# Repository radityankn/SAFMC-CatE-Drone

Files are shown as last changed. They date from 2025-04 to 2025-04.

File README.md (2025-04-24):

# SAFMC-CatE-Drone
A repository for SAFMC Cat E 2025 Drone Design. It consist of Hardware, Software, and Firmware file. The drone is incomplete though, as lack of funds and increased difficulty of development continue to prevent the team from completing it, leading to its early withdrawal from the competition

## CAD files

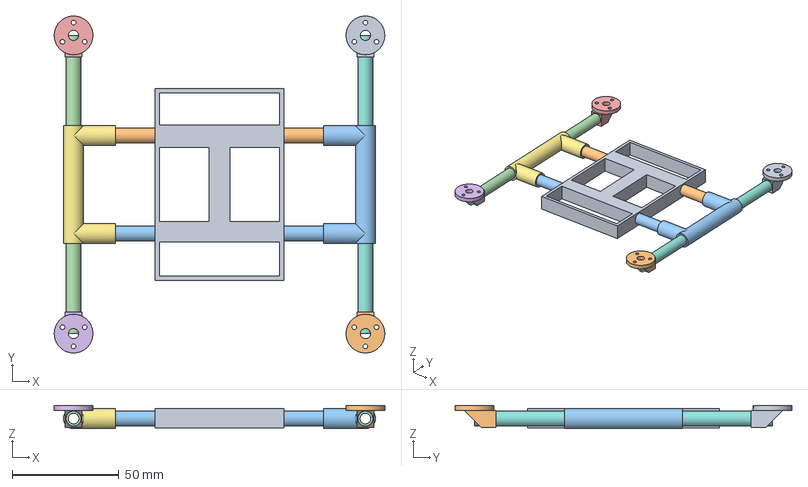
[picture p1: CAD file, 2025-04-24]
Airframe_CatE/Frame Drone_2.FCStd
155.2 x 158.2 x 11.0 mm
Le Platform
Arm_front
Arm_back
Arm_left
Arm_MotorMount001
Arm_MotorMount003
C Joint_Left
Arm_right
Arm_MotorMount
Arm_MotorMount002
C Joint_Right

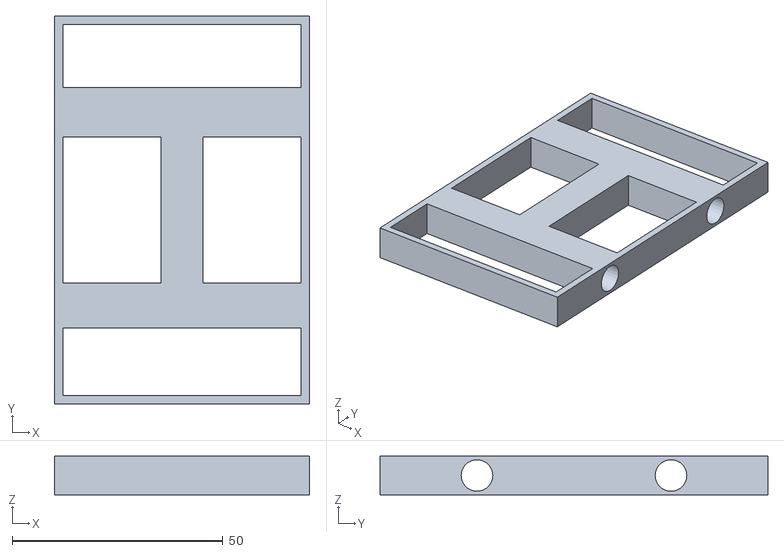
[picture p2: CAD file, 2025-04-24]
STL/Frame Drone_2-Le Platform.stl
60.5 x 92.0 x 9.20

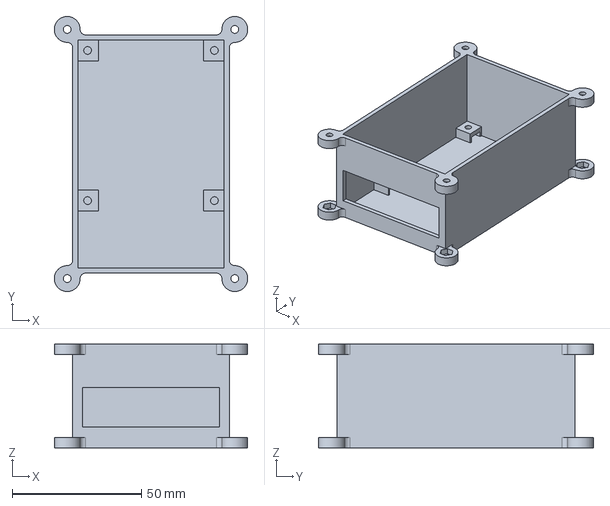
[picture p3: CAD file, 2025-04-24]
Airframe_CatE/new fuselage.FCStd
74.7 x 106.2 x 40.0 mm

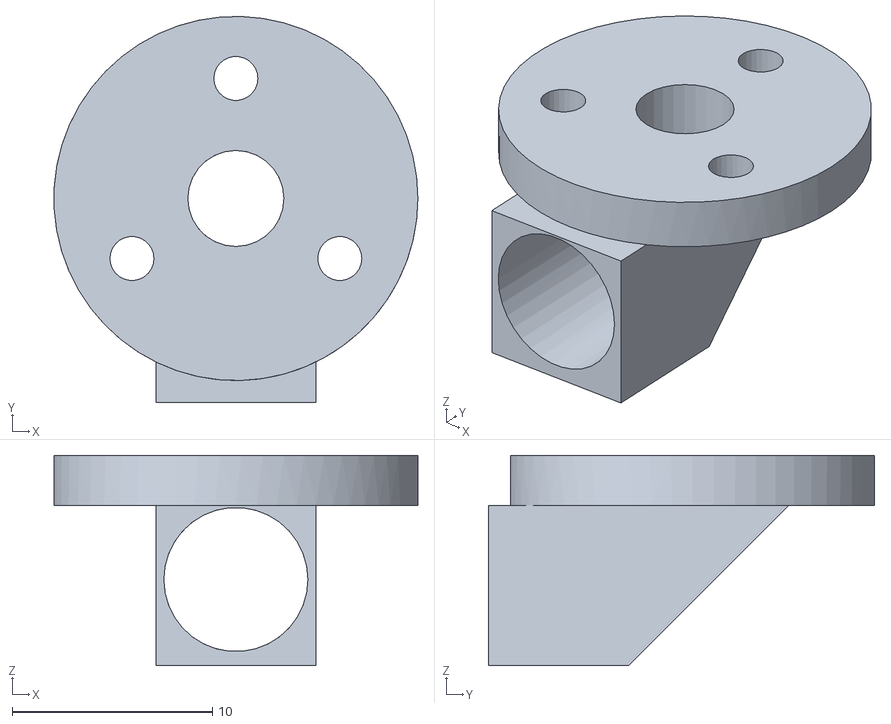
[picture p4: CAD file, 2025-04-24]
STL/Frame Drone_2-Arm_MotorMount.stl
18.2 x 19.3 x 10.5

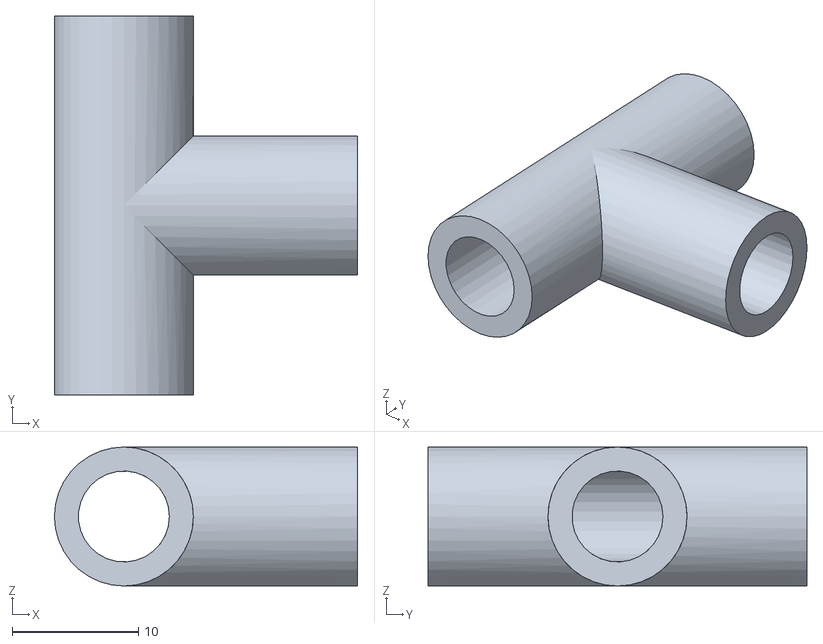
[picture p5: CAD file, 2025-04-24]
STL/Frame Drone_2-T_joint.stl
24.0 x 30.0 x 11.0

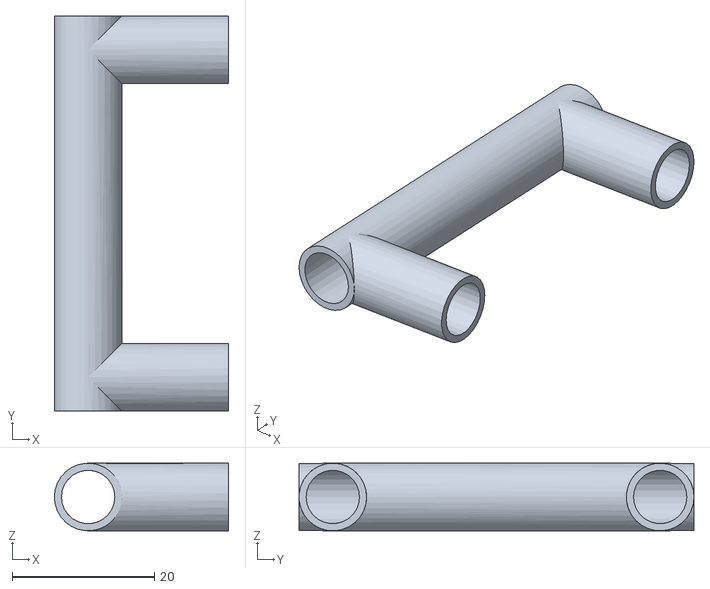
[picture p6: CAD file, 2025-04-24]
STL/Frame Drone_2-Left_motorsC Joint_Left.stl
24.5 x 55.5 x 9.50

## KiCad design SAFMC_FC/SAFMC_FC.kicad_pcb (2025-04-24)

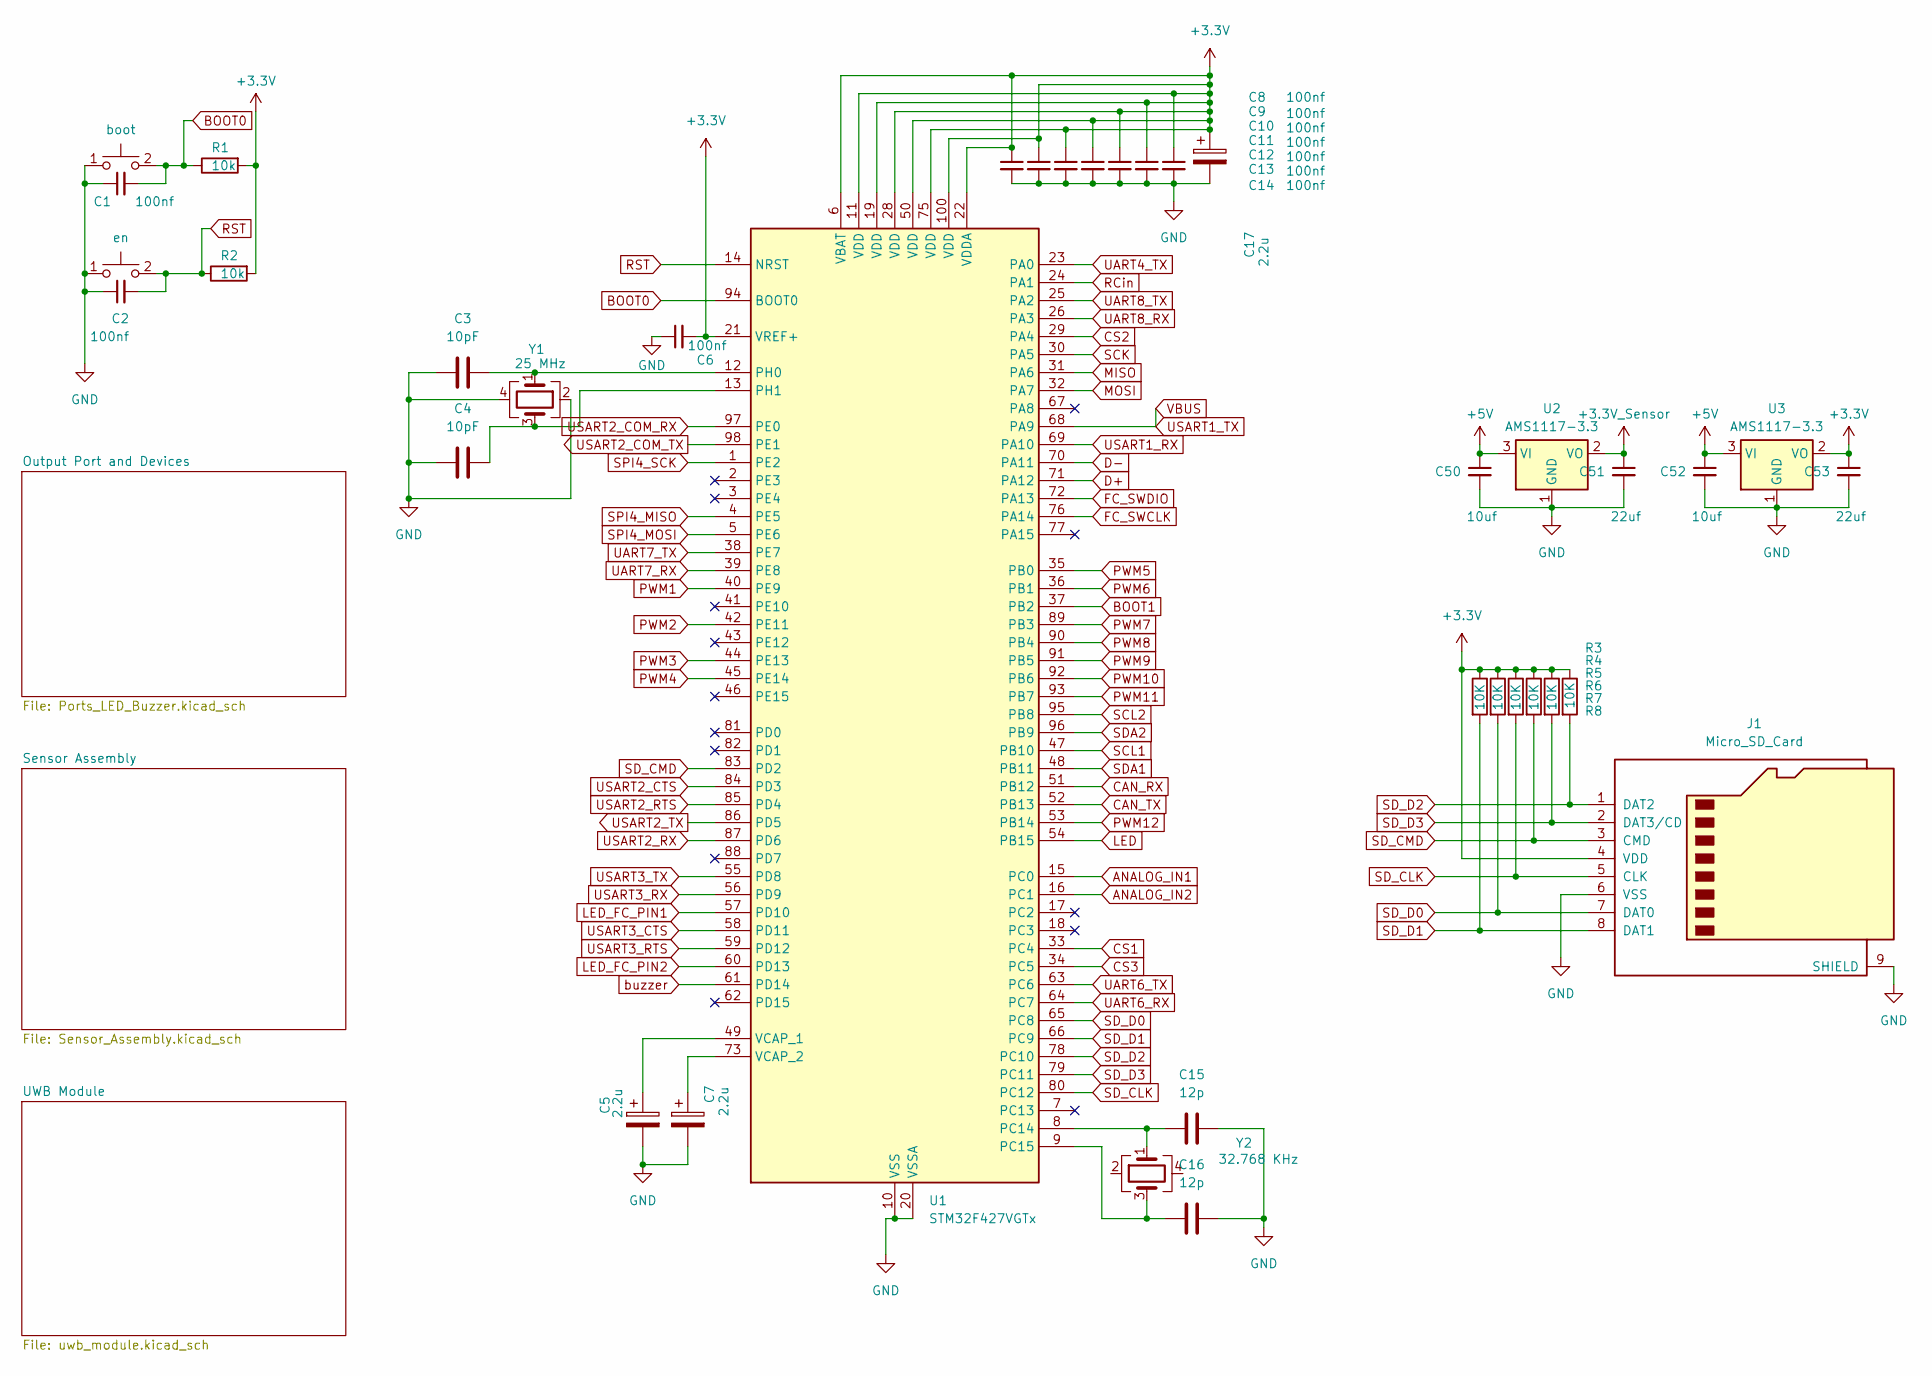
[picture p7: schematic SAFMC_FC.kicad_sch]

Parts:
C1, C2, C6, C8, C9, C10, C11, C12, C13, C14: 100nf; C_0603_1608Metric_Pad1.08x0.95mm_HandSolder
C3, C4: 10pF; C_0603_1608Metric_Pad1.08x0.95mm_HandSolder
C5, C7, C17: 2.2u; C_0603_1608Metric_Pad1.08x0.95mm_HandSolder
C15, C16: 12p; C_0603_1608Metric_Pad1.08x0.95mm_HandSolder
C50, C52: 10uf; C_0805_2012Metric_Pad1.18x1.45mm_HandSolder
C51, C53: 22uf; C_0805_2012Metric_Pad1.18x1.45mm_HandSolder
J1: Micro_SD_Card; microSD_HC_Hirose_DM3BT-DSF-PEJS
R1, R2: 10k; R_0603_1608Metric_Pad0.98x0.95mm_HandSolder
R3, R4, R5, R6, R7, R8: 10K; R_0603_1608Metric_Pad0.98x0.95mm_HandSolder
SW1: boot; SW_Push_SPST_NO_Alps_SKRK
SW2: en; SW_Push_SPST_NO_Alps_SKRK
U1: STM32F427VGTx; LQFP-100_14x14mm_P0.5mm
U2, U3: AMS1117-3.3; SOT-223-3_TabPin2
Y1: 25 MHz; Crystal_SMD_3225-4Pin_3.2x2.5mm_HandSoldering
Y2: 32.768 KHz; Crystal_SMD_SeikoEpson_MC306-4Pin_8.0x3.2mm

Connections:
+3.3V: C6.2, C8.1, C9.1, C10.1, C11.1, C12.1, C13.1, C14.1, C17.1, C53.1, J1.4 (VDD), R1.1, R2.1, R3.1, R4.1, R5.1, R6.1, R7.1, R8.1, U1.6 (VBAT), U1.11 (VDD), U1.19 (VDD), U1.21 (VREF+), U1.22 (VDDA), U1.28 (VDD), U1.50 (VDD), U1.75 (VDD), U1.100 (VDD), U3.2 (VO); also elsewhere on the board
+3.3V_Sensor: C51.1, U2.2 (VO); also elsewhere on the board
+5V: C50.1, C52.1, U2.3 (VI), U3.3 (VI); also elsewhere on the board
ANALOG_IN1: U1.15 (PC0)
ANALOG_IN2: U1.16 (PC1)
BOOT0: C1.2, R1.2, SW1.2 (D), U1.94 (BOOT0)
BOOT1: U1.37 (PB2)
CAN_RX: U1.51 (PB12)
CAN_TX: U1.52 (PB13)
CS1: U1.33 (PC4); also elsewhere on the board
CS2: U1.29 (PA4); also elsewhere on the board
CS3: U1.34 (PC5); also elsewhere on the board
D+: U1.71 (PA12); also elsewhere on the board
D-: U1.70 (PA11); also elsewhere on the board
FC_SWCLK: U1.76 (PA14)
FC_SWDIO: U1.72 (PA13)
GND: C1.1, C2.1, C3.1, C4.1, C5.2, C6.1, C7.2, C8.2, C9.2, C10.2, C11.2, C12.2, C13.2, C14.2, C15.1, C16.1, C17.2, C50.2, C51.2, C52.2, C53.2, J1.6 (VSS), J1.9 (SHIELD), J1.11, SW1.1 (C), SW2.1 (C), U1.10 (VSS), U1.20 (VSSA), U1.27 (VSS), U1.74 (VSS), U1.99 (VSS), U2.1 (GND), U3.1 (GND), Y1.2, Y1.4; also elsewhere on the board
LED: U1.54 (PB15); also elsewhere on the board
LED_FC_PIN1: U1.57 (PD10); also elsewhere on the board
LED_FC_PIN2: U1.60 (PD13); also elsewhere on the board
MISO: U1.31 (PA6); also elsewhere on the board
MOSI: U1.32 (PA7); also elsewhere on the board
unnamed: C15.2, U1.8 (PC14), Y2.1
unnamed: C16.2, U1.9 (PC15), Y2.3
unnamed: C3.2, U1.12 (PH0), Y1.1
unnamed: C4.2, U1.13 (PH1), Y1.3
unnamed: C5.1, U1.49 (VCAP_1)
unnamed: C7.1, U1.73 (VCAP_2)
PWM1: U1.40 (PE9); also elsewhere on the board
PWM2: U1.42 (PE11); also elsewhere on the board
PWM3: U1.44 (PE13); also elsewhere on the board
PWM4: U1.45 (PE14); also elsewhere on the board
PWM5: U1.35 (PB0); also elsewhere on the board
PWM6: U1.36 (PB1); also elsewhere on the board
PWM7: U1.89 (PB3)
PWM8: U1.90 (PB4)
PWM9: U1.91 (PB5)
PWM10: U1.92 (PB6)
PWM11: U1.93 (PB7)
PWM12: U1.53 (PB14)
RCin: U1.24 (PA1); also elsewhere on the board
RST: C2.2, R2.2, SW2.2 (D), U1.14 (NRST)
SCK: U1.30 (PA5); also elsewhere on the board
SCL1: U1.47 (PB10); also elsewhere on the board
SCL2: U1.95 (PB8)
SDA1: U1.48 (PB11); also elsewhere on the board
SDA2: U1.96 (PB9)
SD_CLK: J1.5 (CLK), R5.2, U1.80 (PC12)
SD_CMD: J1.3 (CMD), R6.2, U1.83 (PD2)
SD_D0: J1.7 (DAT0), R4.2, U1.65 (PC8)
SD_D1: J1.8 (DAT1), R3.2, U1.66 (PC9)
SD_D2: J1.1 (DAT2), R8.2, U1.78 (PC10)
SD_D3: J1.2 (DAT3/CD), R7.2, U1.79 (PC11)
SPI4_MISO: U1.4 (PE5)
SPI4_MOSI: U1.5 (PE6)
SPI4_SCK: U1.1 (PE2)
UART4_TX: U1.23 (PA0)
UART6_RX: U1.64 (PC7)
UART6_TX: U1.63 (PC6)
UART7_RX: U1.39 (PE8)
UART7_TX: U1.38 (PE7)
UART8_RX: U1.26 (PA3)
UART8_TX: U1.25 (PA2)
USART1_RX: U1.69 (PA10)
USART1_TX: U1.68 (PA9); also elsewhere on the board
USART2_COM_RX: U1.97 (PE0); also elsewhere on the board
USART2_COM_TX: U1.98 (PE1); also elsewhere on the board
USART2_CTS: U1.84 (PD3)
USART2_RTS: U1.85 (PD4)
USART2_RX: U1.87 (PD6)
USART2_TX: U1.86 (PD5)
USART3_CTS: U1.58 (PD11)
USART3_RTS: U1.59 (PD12)
USART3_RX: U1.56 (PD9)
USART3_TX: U1.55 (PD8)
buzzer: U1.61 (PD14); also elsewhere on the board

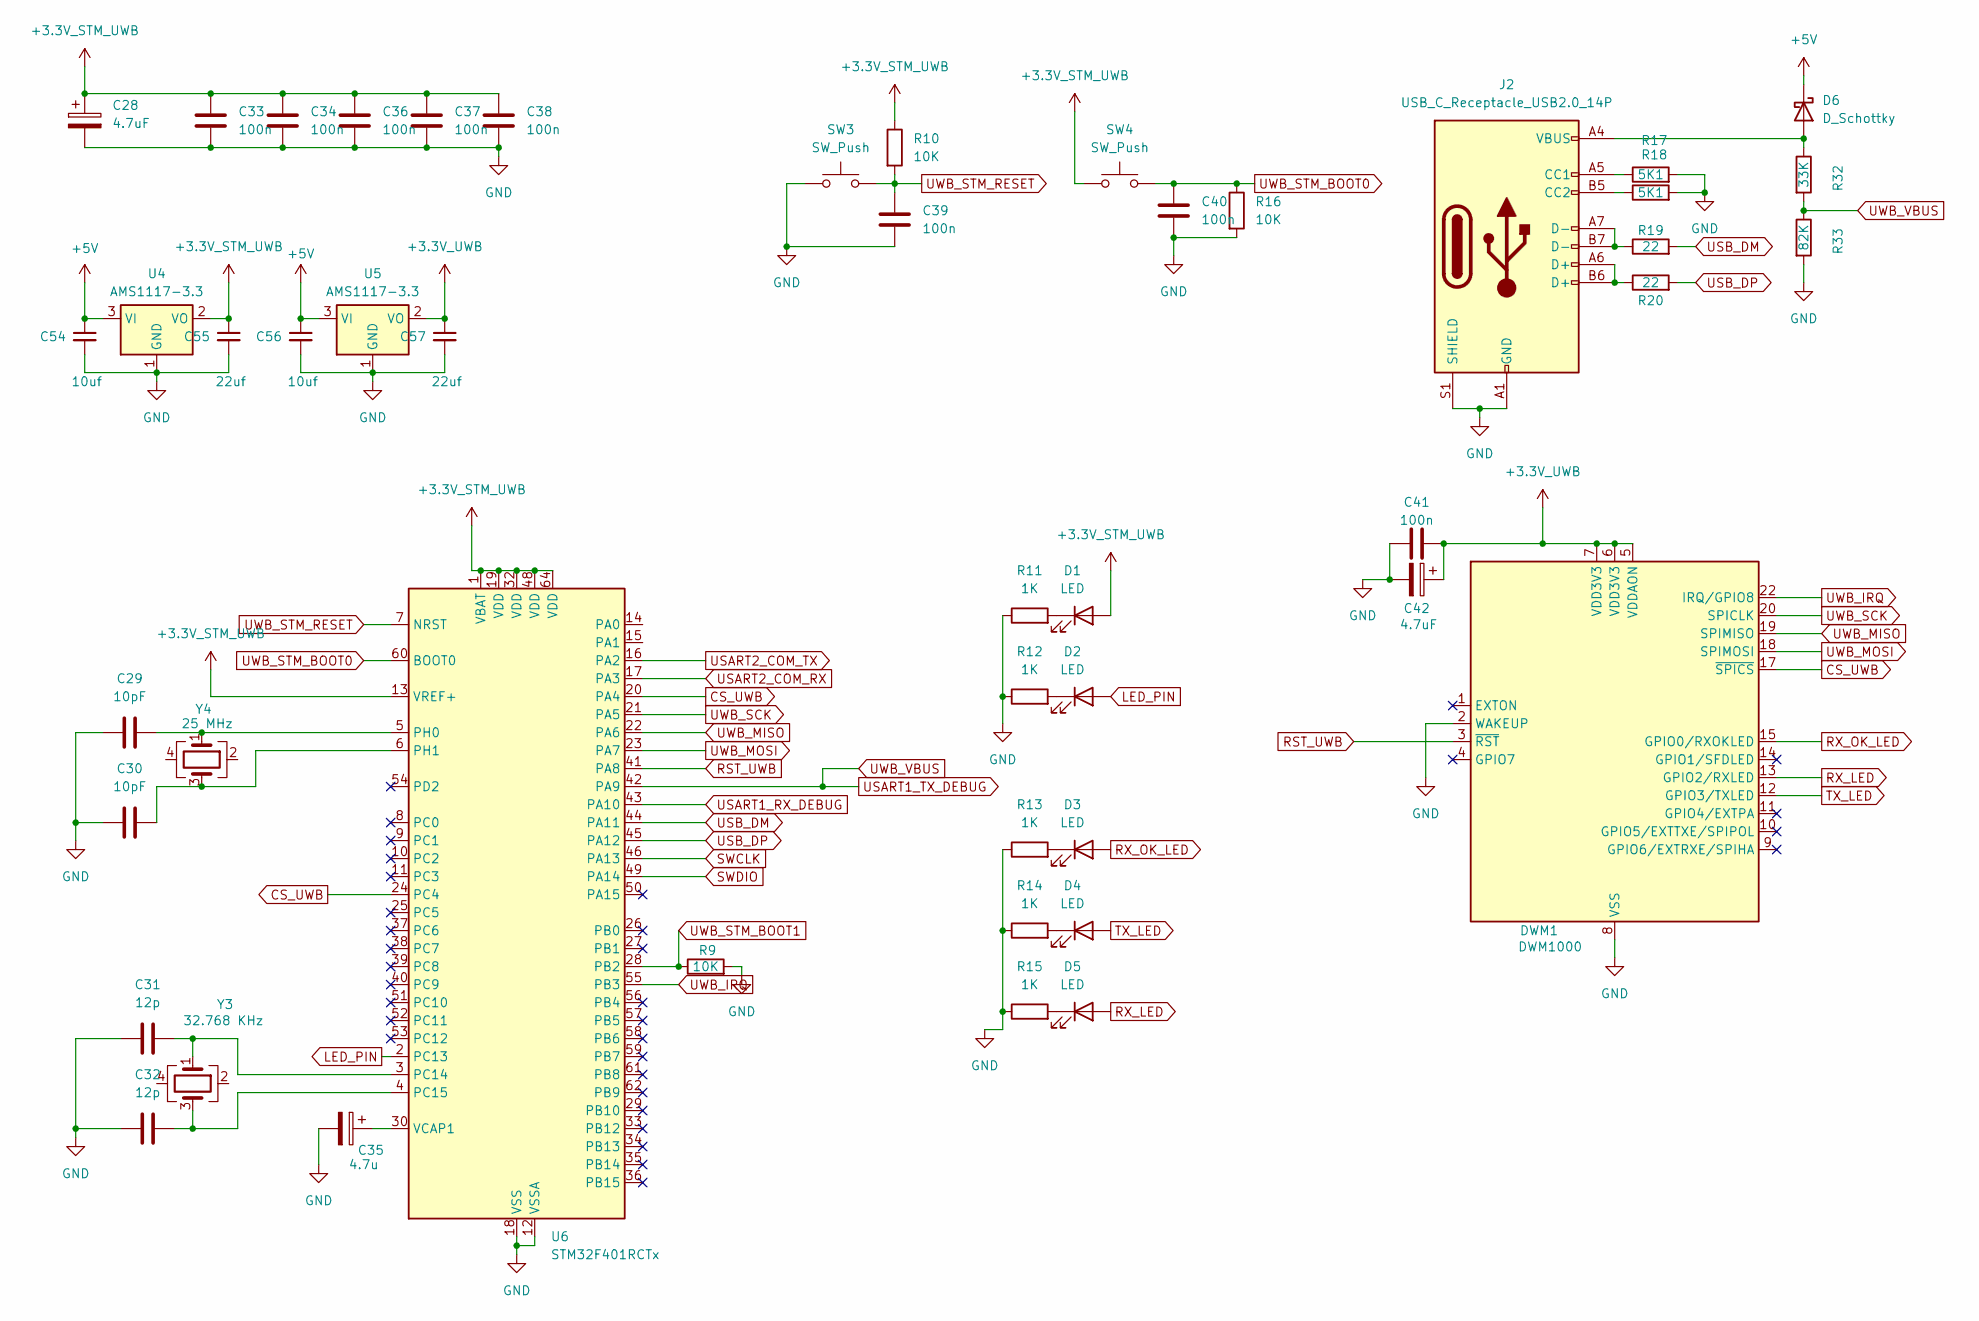
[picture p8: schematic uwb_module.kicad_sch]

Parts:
C28, C42: 4.7uF; C_0603_1608Metric_Pad1.08x0.95mm_HandSolder
C29, C30: 10pF; C_0603_1608Metric_Pad1.08x0.95mm_HandSolder
C31, C32: 12p; C_0603_1608Metric_Pad1.08x0.95mm_HandSolder
C33, C34, C36, C37, C38, C39, C40, C41: 100n; C_0603_1608Metric_Pad1.08x0.95mm_HandSolder
C35: 4.7u; C_0603_1608Metric_Pad1.08x0.95mm_HandSolder
C54, C56: 10uf; C_0805_2012Metric_Pad1.18x1.45mm_HandSolder
C55, C57: 22uf; C_0805_2012Metric_Pad1.18x1.45mm_HandSolder
D1, D2, D3, D4, D5: LED; LED_0603_1608Metric_Pad1.05x0.95mm_HandSolder
D6: D_Schottky; D_SOD-323F
DWM1: DWM1000
J2: USB_C_Receptacle_USB2.0_14P; USB_C_Receptacle_JAE_DX07S016JA1R1500
R9, R10, R16: 10K; R_0603_1608Metric_Pad0.98x0.95mm_HandSolder
R11, R12, R13, R14, R15: 1K; R_0603_1608Metric_Pad0.98x0.95mm_HandSolder
R17, R18: 5K1; R_0603_1608Metric_Pad0.98x0.95mm_HandSolder
R19, R20: 22; R_0603_1608Metric_Pad0.98x0.95mm_HandSolder
R32: 33K; R_0603_1608Metric_Pad0.98x0.95mm_HandSolder
R33: 82K; R_0603_1608Metric_Pad0.98x0.95mm_HandSolder
SW3, SW4: SW_Push; SW_Push_SPST_NO_Alps_SKRK
U4, U5: AMS1117-3.3; SOT-223-3_TabPin2
U6: STM32F401RCTx; LQFP-64_10x10mm_P0.5mm
Y3: 32.768 KHz; Crystal_SMD_SeikoEpson_MC306-4Pin_8.0x3.2mm
Y4: 25 MHz; Crystal_SMD_3225-4Pin_3.2x2.5mm_HandSoldering

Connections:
+3.3V_STM_UWB: C28.1, C33.2, C34.2, C36.2, C37.2, C38.2, C55.1, D1.2 (A), R10.1, SW4.1, U4.2 (VO), U6.1 (VBAT), U6.13 (VREF+), U6.19 (VDD), U6.32 (VDD), U6.48 (VDD), U6.64 (VDD)
+3.3V_UWB: C41.1, C42.1, C57.1, DWM1.5 (VDDAON), DWM1.6 (VDD3V3), DWM1.7 (VDD3V3), U5.2 (VO)
+5V: C54.1, C56.1, D6.1 (K), U4.3 (VI), U5.3 (VI); also elsewhere on the board
CS_UWB: DWM1.17 (~SPICS), U6.20 (PA4), U6.24 (PC4)
GND: C28.2, C29.1, C30.1, C31.1, C32.1, C33.1, C34.1, C35.2, C36.1, C37.1, C38.1, C39.1, C40.1, C41.2, C42.2, C54.2, C55.2, C56.2, C57.2, DWM1.2 (WAKEUP), DWM1.8 (VSS), DWM1.16 (VSS), DWM1.21 (VSS), DWM1.23 (VSS), DWM1.24 (VSS), J2.A1 (GND), J2.A12 (GND), J2.B1 (GND), J2.B12 (GND), J2.S1 (SHIELD), R9.2, R11.1, R12.1, R13.1, R14.1, R15.1, R16.2, R17.2, R18.2, R33.2, SW3.1, U4.1 (GND), U5.1 (GND), U6.12 (VSSA), U6.18 (VSS), U6.31 (VSS), U6.47 (VSS), U6.63 (VSS); also elsewhere on the board
LED_PIN: D2.2 (A), U6.2 (PC13)
unnamed: D1.1 (K), R11.2
unnamed: D2.1 (K), R12.2
unnamed: D3.1 (K), R13.2
unnamed: D4.1 (K), R14.2
unnamed: D5.1 (K), R15.2
unnamed: D6.2 (A), J2.A4 (VBUS), J2.A9 (VBUS), J2.B4 (VBUS), J2.B9 (VBUS), R32.1
unnamed: J2.A5 (CC1), R17.1
unnamed: J2.B5 (CC2), R18.1
unnamed: J2.A6 (D+), J2.B6 (D+), R20.1
unnamed: J2.A7 (D-), J2.B7 (D-), R19.1
unnamed: C31.2, U6.3 (PC14), Y3.1
unnamed: C32.2, U6.4 (PC15), Y3.3
unnamed: C29.2, U6.5 (PH0), Y4.1
unnamed: C30.2, U6.6 (PH1), Y4.3
unnamed: C35.1, U6.30 (VCAP1)
RST_UWB: DWM1.3 (~RST), U6.41 (PA8)
RX_LED: D5.2 (A), DWM1.13 (GPIO2/RXLED)
RX_OK_LED: D3.2 (A), DWM1.15 (GPIO0/RXOKLED)
SWCLK: U6.46 (PA13)
SWDIO: U6.49 (PA14)
TX_LED: D4.2 (A), DWM1.12 (GPIO3/TXLED)
USART1_RX_DEBUG: U6.43 (PA10)
USART1_TX_DEBUG: R32.2, R33.1, U6.42 (PA9)
USART2_COM_RX: U6.17 (PA3); also elsewhere on the board
USART2_COM_TX: U6.16 (PA2); also elsewhere on the board
USB_DM: R19.2, U6.44 (PA11)
USB_DP: R20.2, U6.45 (PA12)
UWB_IRQ: DWM1.22 (IRQ/GPIO8), U6.55 (PB3)
UWB_MISO: DWM1.19 (SPIMISO), U6.22 (PA6)
UWB_MOSI: DWM1.18 (SPIMOSI), U6.23 (PA7)
UWB_SCK: DWM1.20 (SPICLK), U6.21 (PA5)
UWB_STM_BOOT0: C40.2, R16.1, SW4.2, U6.60 (BOOT0)
UWB_STM_BOOT1: R9.1, U6.28 (PB2)
UWB_STM_RESET: C39.2, R10.2, SW3.2, U6.7 (NRST)

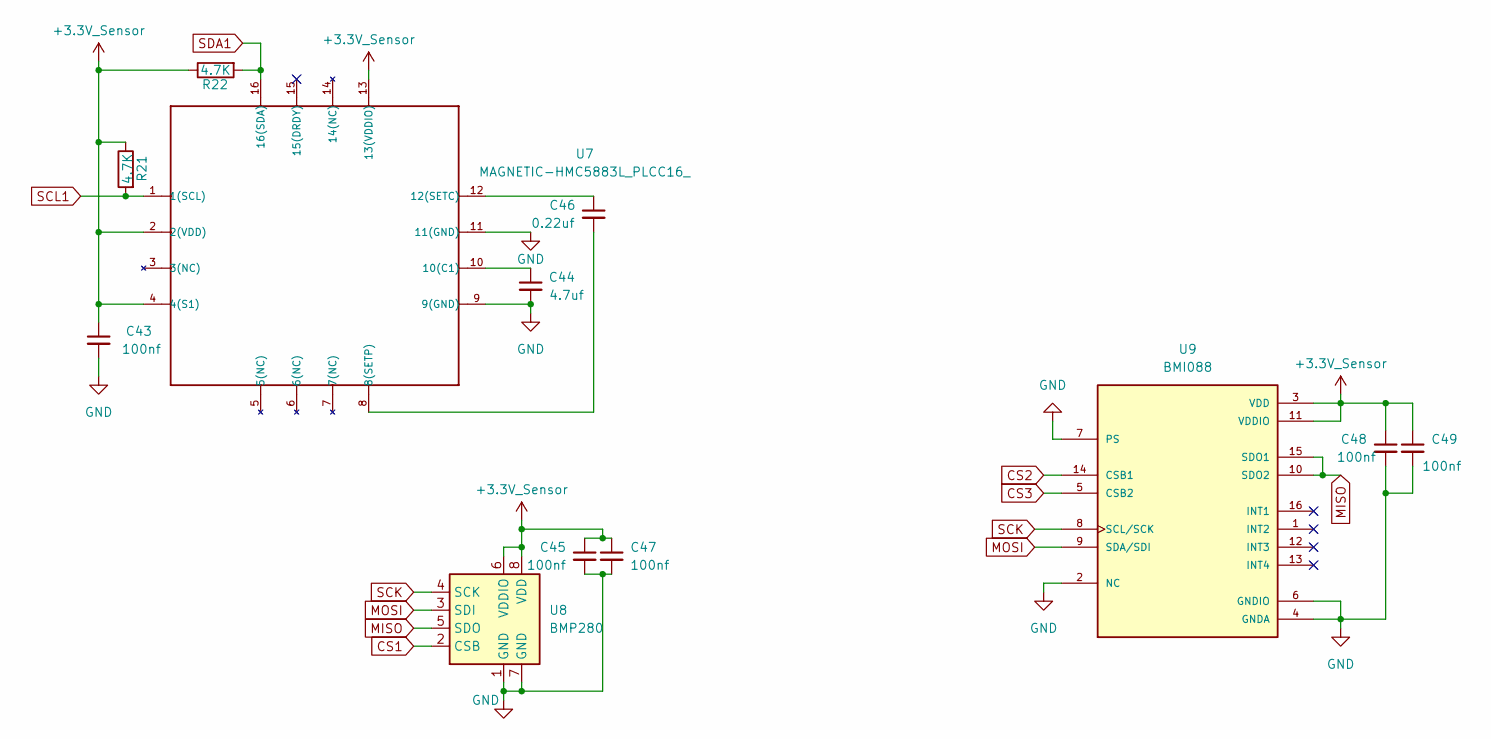
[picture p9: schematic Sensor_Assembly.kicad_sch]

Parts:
C43, C45, C47, C48, C49: 100nf; C_0603_1608Metric_Pad1.08x0.95mm_HandSolder
C44: 4.7uf; C_0603_1608Metric_Pad1.08x0.95mm_HandSolder
C46: 0.22uf; C_0805_2012Metric_Pad1.18x1.45mm_HandSolder
R21, R22: 4.7K; R_0603_1608Metric_Pad0.98x0.95mm_HandSolder
U7: MAGNETIC-HMC5883L_PLCC16_; PLCC16-0.5-3X3MM; MPN HMC5883L
U8: BMP280; Bosch_LGA-8_2x2.5mm_P0.65mm_ClockwisePinNumbering
U9: BMI088; PQFN50P450X300X100-16N

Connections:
+3.3V_Sensor: C43.1, C45.1, C47.1, C48.1, C49.1, R21.2, R22.2, U7.2 (2(VDD)), U7.4 (4(S1)), U7.13 (13(VDDIO)), U8.6 (VDDIO), U8.8 (VDD), U9.3 (VDD), U9.11 (VDDIO); also elsewhere on the board
CS1: U8.2 (CSB); also elsewhere on the board
CS2: U9.14 (CSB1); also elsewhere on the board
CS3: U9.5 (CSB2); also elsewhere on the board
GND: C43.2, C44.2, C45.2, C47.2, C48.2, C49.2, U7.9 (9(GND)), U7.11 (11(GND)), U8.1 (GND), U8.7 (GND), U9.2 (NC), U9.4 (GNDA), U9.6 (GNDIO), U9.7 (PS); also elsewhere on the board
MISO: U8.5 (SDO), U9.10 (SDO2), U9.15 (SDO1); also elsewhere on the board
MOSI: U8.3 (SDI), U9.9 (SDA/SDI); also elsewhere on the board
unnamed: C46.2, U7.8 (8(SETP))
unnamed: C44.1, U7.10 (10(C1))
unnamed: C46.1, U7.12 (12(SETC))
SCK: U8.4 (SCK), U9.8 (SCL/SCK); also elsewhere on the board
SCL1: R21.1, U7.1 (1(SCL)); also elsewhere on the board
SDA1: R22.1, U7.16 (16(SDA)); also elsewhere on the board

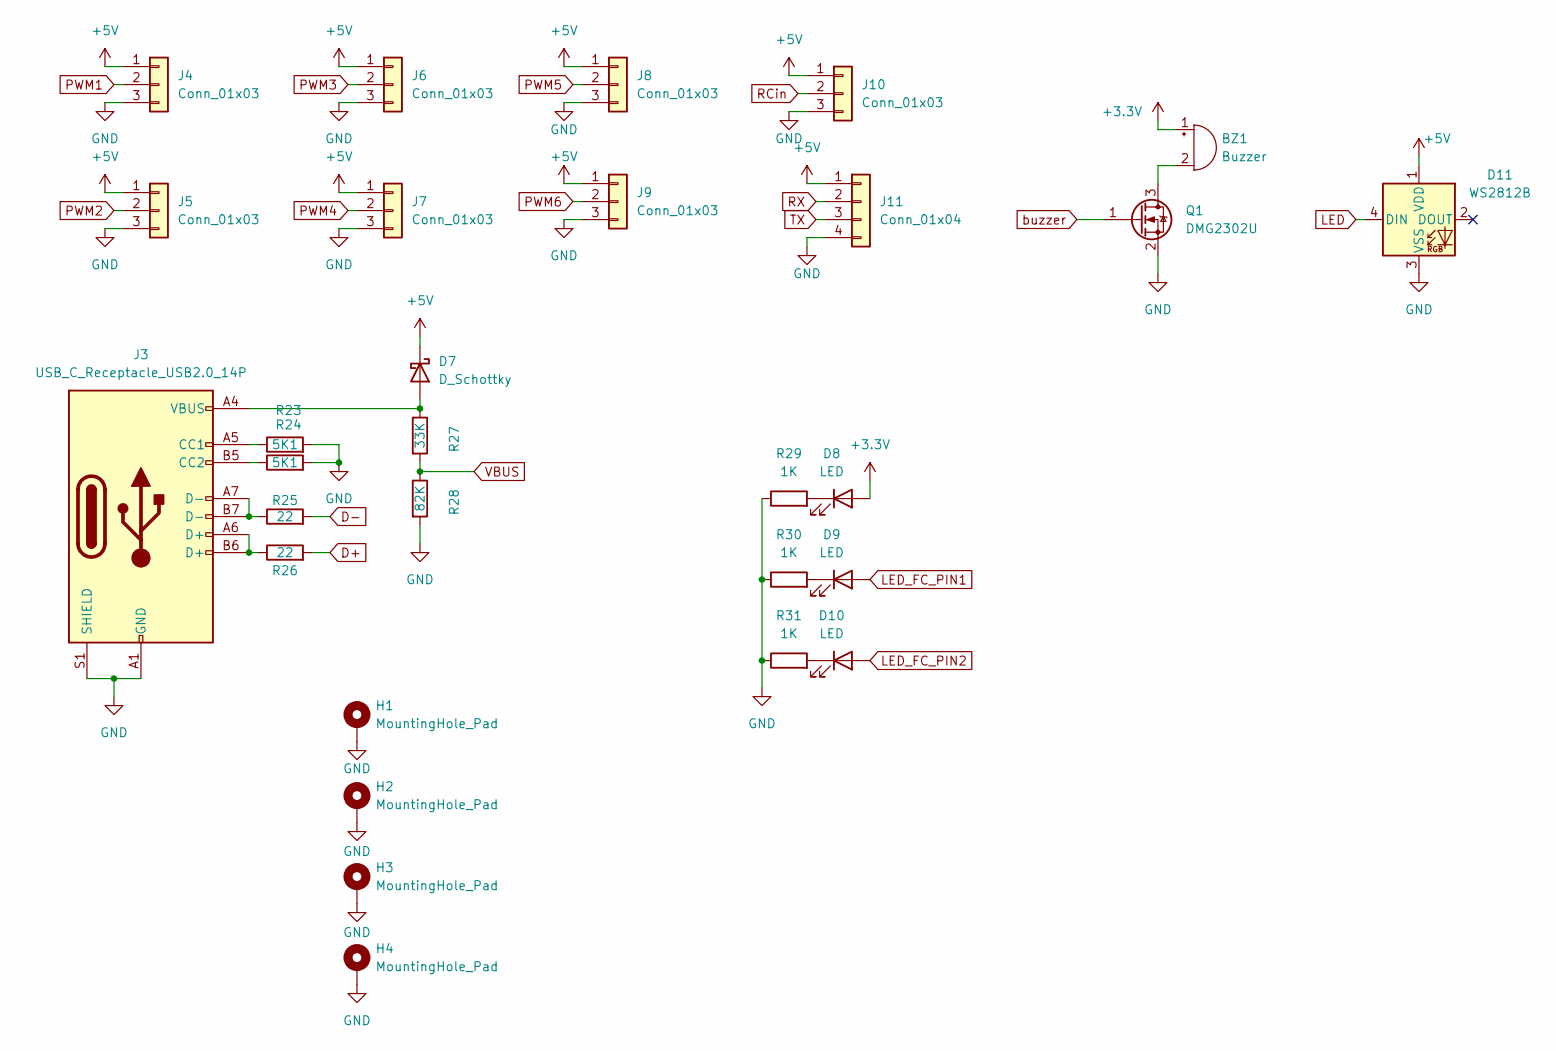
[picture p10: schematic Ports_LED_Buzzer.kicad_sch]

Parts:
BZ1: Buzzer
D7: D_Schottky; D_SOD-323F
D8, D9, D10: LED; LED_0603_1608Metric_Pad1.05x0.95mm_HandSolder
D11: WS2812B; LED_WS2812B_PLCC4_5.0x5.0mm_P3.2mm
H1, H2, H3, H4: MountingHole_Pad; MountingHole_2.7mm_M2.5_Pad
J3: USB_C_Receptacle_USB2.0_14P; USB_C_Receptacle_JAE_DX07S016JA1R1500
J4, J5, J6, J7, J8, J9, J10: Conn_01x03; PinHeader_1x03_P2.54mm_Vertical; Part Number 1-0301FBV0T
J11: Conn_01x04; JST_XH_B4B-XH-A_1x04_P2.50mm_Vertical; Part Number 1-0401FBV0T
Q1: DMG2302U; SOT-23
R23, R24: 5K1; R_0603_1608Metric_Pad0.98x0.95mm_HandSolder
R25, R26: 22; R_0603_1608Metric_Pad0.98x0.95mm_HandSolder
R27: 33K; R_0603_1608Metric_Pad0.98x0.95mm_HandSolder
R28: 82K; R_0603_1608Metric_Pad0.98x0.95mm_HandSolder
R29, R30, R31: 1K; R_0603_1608Metric_Pad0.98x0.95mm_HandSolder

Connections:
+3.3V: BZ1.1 (+), D8.2 (A); also elsewhere on the board
+5V: D7.1 (K), D11.1 (VDD), J4.1, J5.1, J6.1, J7.1, J8.1, J9.1, J10.1, J11.1; also elsewhere on the board
D+: R26.2; also elsewhere on the board
D-: R25.2; also elsewhere on the board
GND: D11.3 (VSS), H1.1, H2.1, H3.1, H4.1, J3.A1 (GND), J3.A12 (GND), J3.B1 (GND), J3.B12 (GND), J3.S1 (SHIELD), J4.3, J5.3, J6.3, J7.3, J8.3, J9.3, J10.3, J11.4, Q1.2 (S), R23.2, R24.2, R28.2, R29.1, R30.1, R31.1; also elsewhere on the board
LED: D11.4 (DIN); also elsewhere on the board
LED_FC_PIN1: D9.2 (A); also elsewhere on the board
LED_FC_PIN2: D10.2 (A); also elsewhere on the board
unnamed: BZ1.2 (-), Q1.3 (D)
unnamed: D7.2 (A), J3.A4 (VBUS), J3.A9 (VBUS), J3.B4 (VBUS), J3.B9 (VBUS), R27.1
unnamed: D8.1 (K), R29.2
unnamed: D9.1 (K), R30.2
unnamed: D10.1 (K), R31.2
unnamed: J3.A5 (CC1), R23.1
unnamed: J3.B5 (CC2), R24.1
unnamed: J3.A6 (D+), J3.B6 (D+), R26.1
unnamed: J3.A7 (D-), J3.B7 (D-), R25.1
PWM1: J4.2; also elsewhere on the board
PWM2: J5.2; also elsewhere on the board
PWM3: J6.2; also elsewhere on the board
PWM4: J7.2; also elsewhere on the board
PWM5: J8.2; also elsewhere on the board
PWM6: J9.2; also elsewhere on the board
RCin: J10.2; also elsewhere on the board
RX: J11.2
TX: J11.3
USART1_TX: R27.2, R28.1; also elsewhere on the board
buzzer: Q1.1 (G); also elsewhere on the board

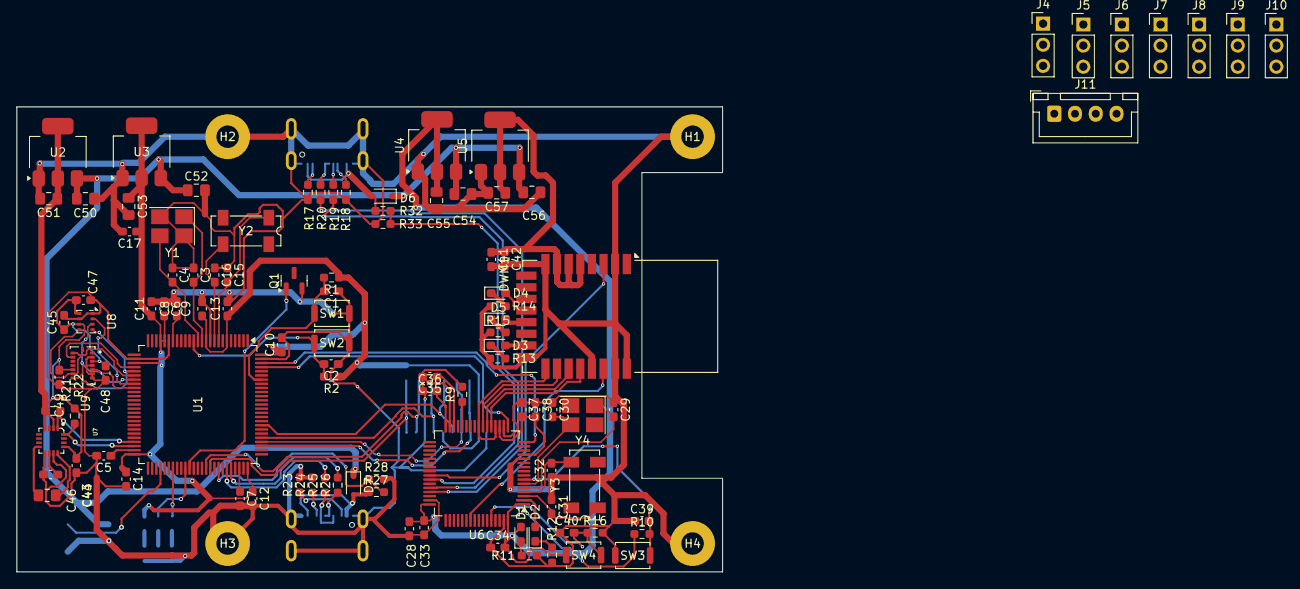
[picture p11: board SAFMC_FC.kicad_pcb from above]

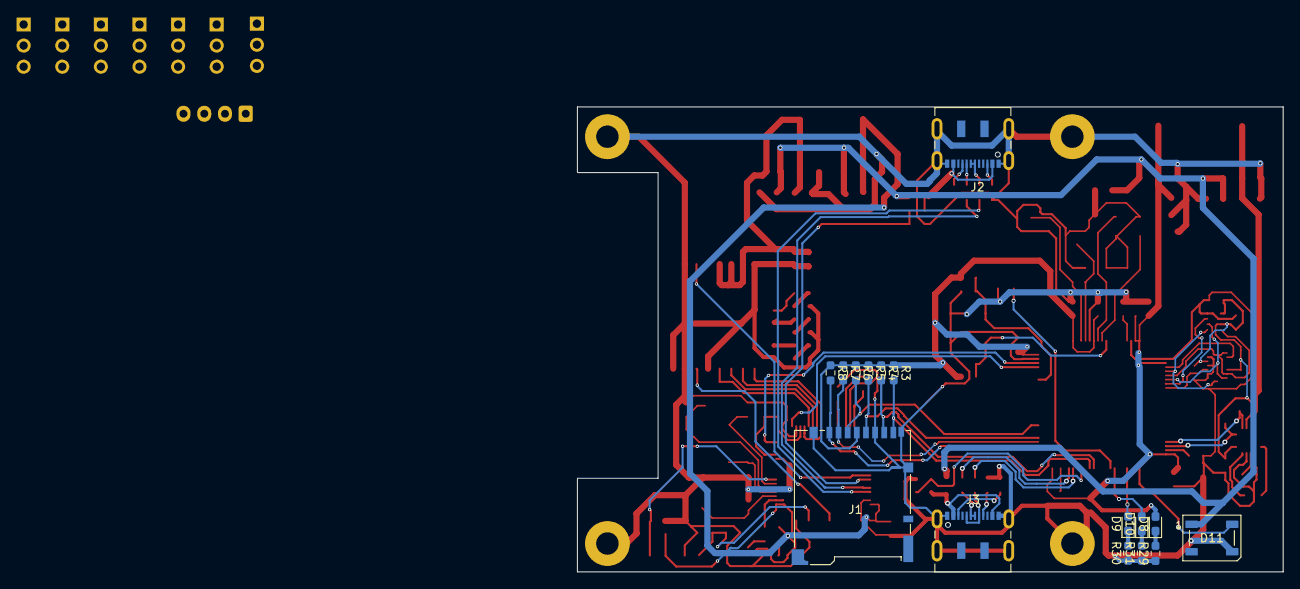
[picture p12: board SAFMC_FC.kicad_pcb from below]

Board: 4 copper layers, 85.0 x 56.0 mm, 125 parts (16 on the bottom side), 86 nets.
